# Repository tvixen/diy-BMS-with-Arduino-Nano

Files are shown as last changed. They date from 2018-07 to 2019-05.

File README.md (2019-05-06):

## Update 12/3-2019

New PCB version 3.0.8 added. Including gerber files for PCB in .zip file.

## Update 30/11-2018
Final slave module is ready and running. Software has been updated on slaves and master. Big packs of 100 cells, has been added. 
Pictures:
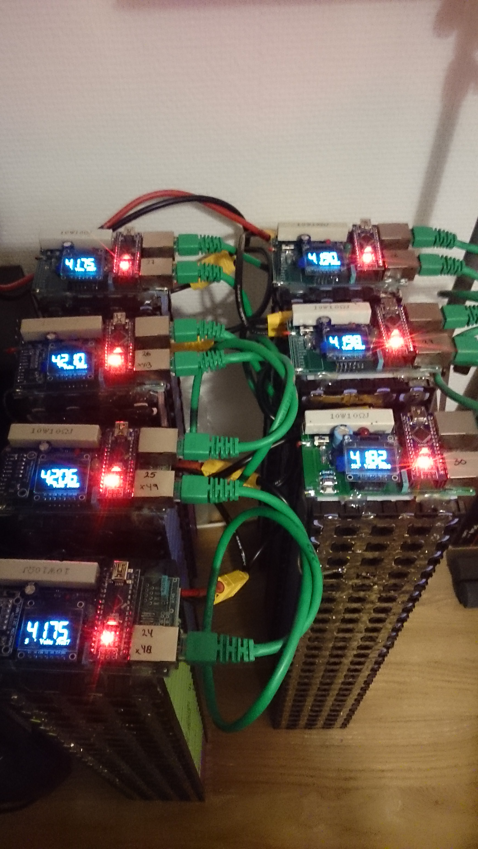
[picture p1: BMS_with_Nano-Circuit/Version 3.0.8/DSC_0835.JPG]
Figure what


## Update 13/7-2018

Arduino code for Master is uploaded. It's purly working as master, and without any debug information. But it should be plug'n play.
Arduino code for Slave is uploaded. No really debug information in code.

## Update 11/7-2018

Feel free to add comments or copy the whole project. It will be updated continuously.....
Next update will be the code for the Master and Slave.
Hardware drawings was updated to 3.0.4

-------------------------------------------------------------------------------------------------------------------------------

# Project "diyBMS with Arduino Nano" (11/7-2018)
Do it yourself battery management system to Lithium ion battery packs/cells
Inspired by Stuart Pittaway, and therefore the credit goes to him.

I was building a powerwall, and for that I needed a sort of batteri management. I have had a look at Batrium, but they was located in the US and the import would be to costly. So I found 
Stuart's project and thourght "This could work". But I was in need of a display and a precise 16bit ADC, so I found some cheap alternatives and added them to the circuit. A new PCB was now under construction.
Then I ordered the parts, and for my big surprise there were no power supply chips or ATtiny85 chips on the marked. So I decided to change the design and use what I had in the drawer. A handful of Arduino Nano.
So therefore this project is designed around the Arduino Nano with a boot sector from the Optiboot project. (no big deal of burning an ordinary Nano with Optiboot) 
The features are also a little different from the original project, as I’m not using the ESP8266 with Wifi, so there will be no transmitting data to a web interface.
Instead the slave modules can show the value of the battery pack (very precise), and the module number itself. The Master will show the status of all the modules, and also send balance commands 
to the module who is sticking out from rest of the packs/cells. + Every module will check if the voltage is over 4.200 volts and balance itself if needed. 

# The design

* One central controller and up to 24 individual cell monitoring nodes.
* The PCB is intented to be sitting in front of a batteri pack with 100.pcs 18650 cells, soldered together with fuses of 1.amp each.
* Use Arduino code, libraries and tools
* Use Arduino Nano as the Master and Slave, so a single PCB can be used as both Master or Slave. 
* Use good connection cables with low noise (twisted pairs)
* The Master will monitoring and control the slaves on the bus.
* The Slave will monitor itself, and discharge if the voltage is higer than 4.200 volts.
* Every single slave will show the pack voltage and the module number on the LED display.
* Ensure each cell voltage is isolated from other cells and that ground voltage is isolated
* Ensure communications between controller and node is isolated
* Keep the coste to a minimum and use whatever theres in the drawer.

# The code

* I did try to use as much of Stuart's origianal code as possible, but had to add a lot of stuff 
* keep it short and simple
* Try not to do inline stuff, as this can be difficult to convert to other platforms/chips

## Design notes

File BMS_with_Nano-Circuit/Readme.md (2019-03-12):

# New PCB files added 12/3-2019

Download the .zip file for the PCB files version 3.0.8.zip

 * "Version 3.0.8"
 
https://github.com/tvixen/diy-BMS-with-Arduino-Nano/blob/master/BMS_with_Nano-Circuit/Version%203.0.8/3.0.8.zip

Pictures for this version:

Figure what

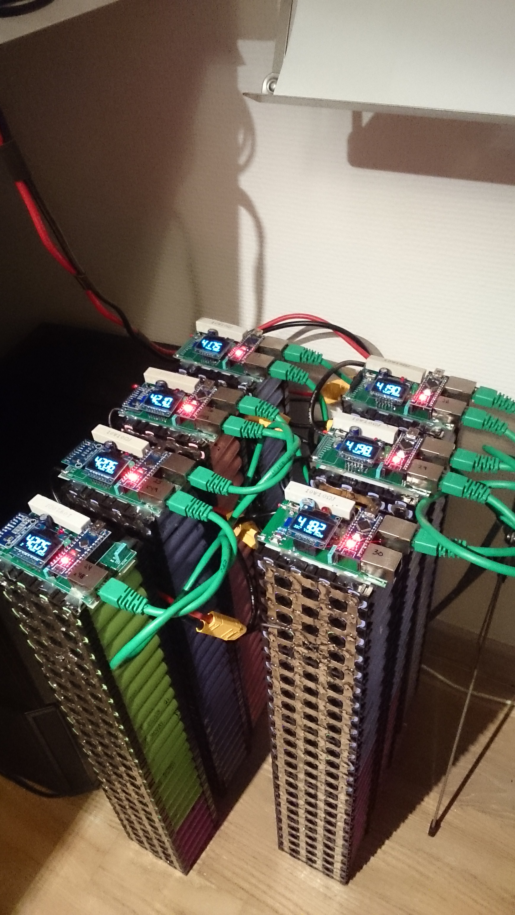
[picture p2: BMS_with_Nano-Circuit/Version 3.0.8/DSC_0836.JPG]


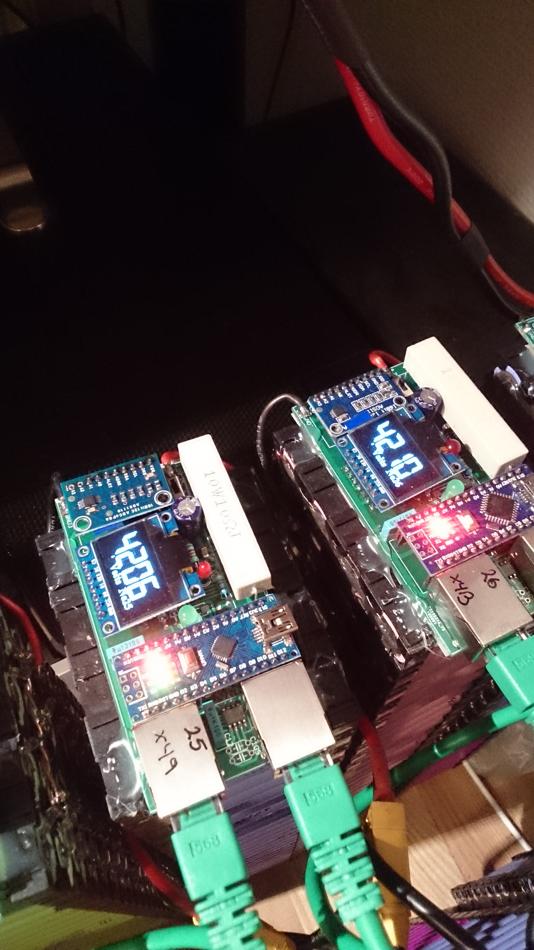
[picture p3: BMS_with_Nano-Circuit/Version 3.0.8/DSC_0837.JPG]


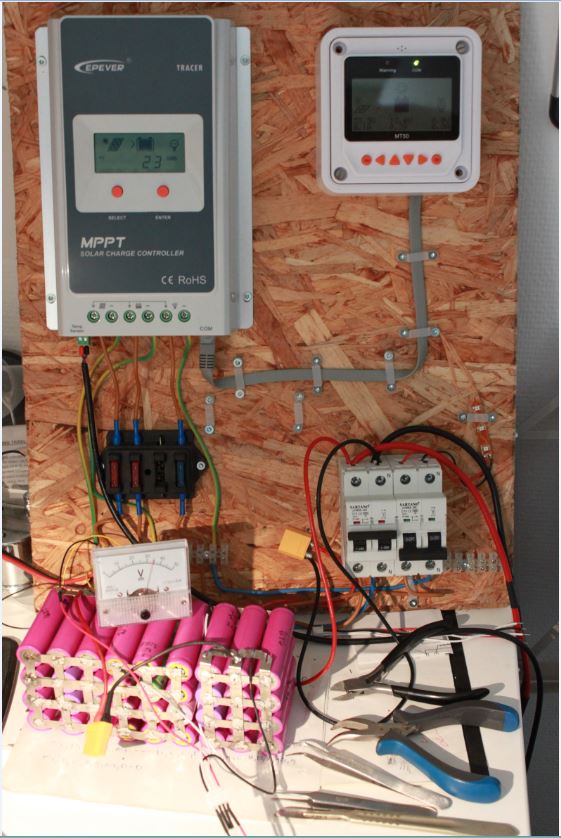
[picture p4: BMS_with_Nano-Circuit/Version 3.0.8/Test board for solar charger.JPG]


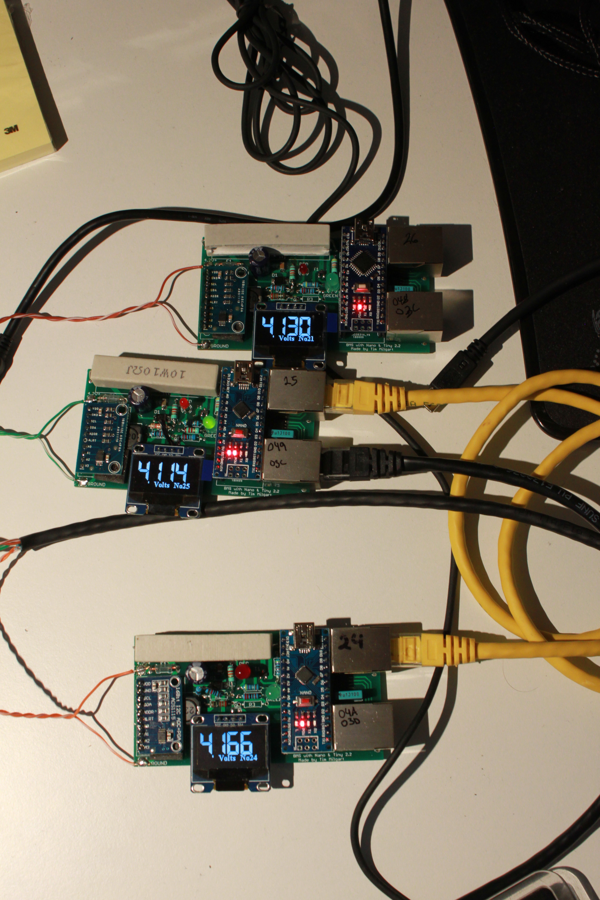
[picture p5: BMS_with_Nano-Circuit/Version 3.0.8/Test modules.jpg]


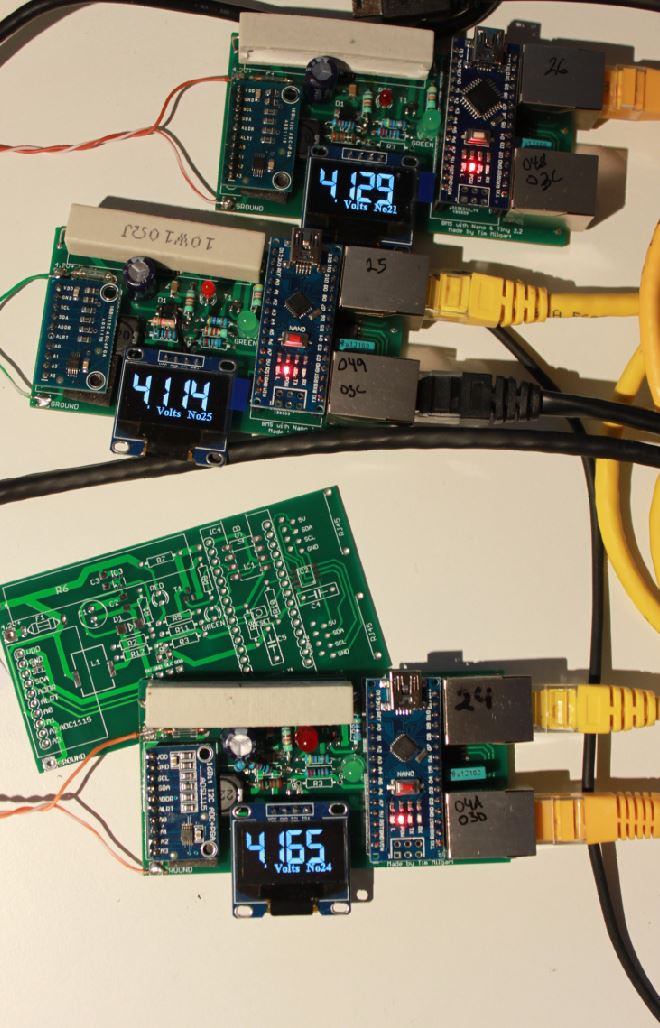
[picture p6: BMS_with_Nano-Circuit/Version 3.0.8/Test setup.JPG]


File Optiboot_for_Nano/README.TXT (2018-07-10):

This is an Optiboot version 6.2 JSON link to put in your Arduino preferences: 
https://github.com/Optiboot/optiboot/releases/download/v6.2/package_optiboot_optiboot-additional_index.json

This is a link to the "Use Arduino as ISP (burner) tutorial:https://www.arduino.cc/en/Tutorial/ArduinoISP

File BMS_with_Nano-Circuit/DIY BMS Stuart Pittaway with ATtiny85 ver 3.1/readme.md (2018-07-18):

# 18/7-2018
New board made with smaller foot print 40*78mm, and now with holes for mounting on 3D printed holder.
Use Stuart's code for this print.

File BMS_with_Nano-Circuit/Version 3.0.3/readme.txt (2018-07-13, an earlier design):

1. The ATTiny85 is now removed. Nano is extreem easy to get on Ebay. AtTiny85 is NOT. 
2. I2C Dispaly is replaced with a SPI Display, to make as little disturbance on the I2C bus as possible. 
3. ADUM1250 is now mounted correct.
4. Added new values to resistors and caps.

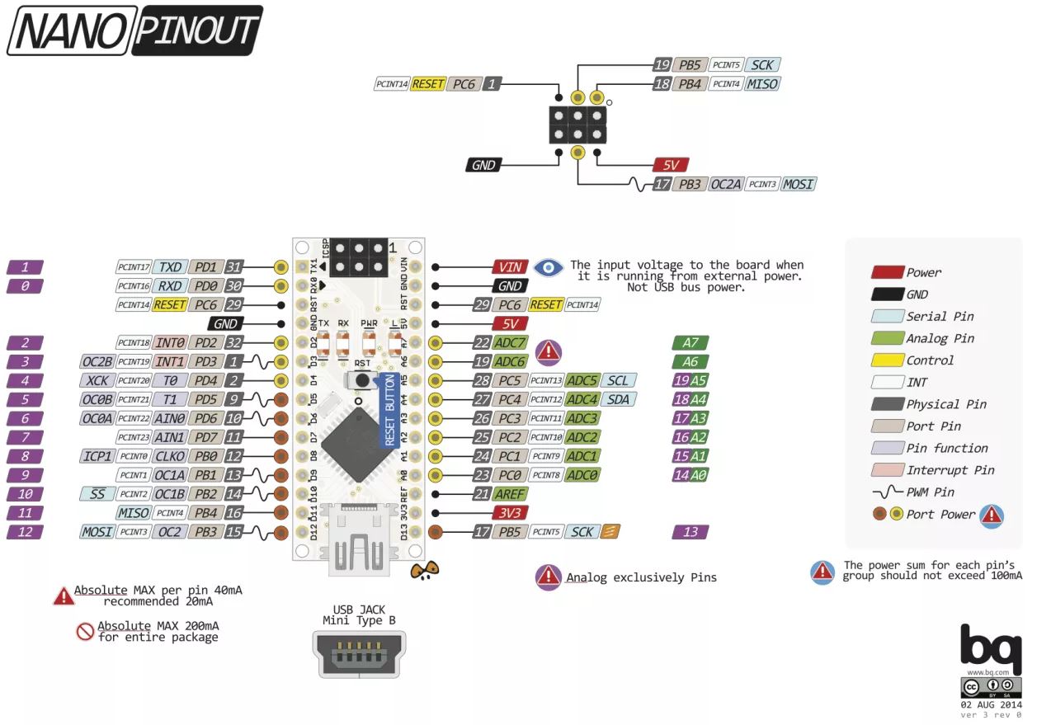
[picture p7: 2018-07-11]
BMS_with_Nano-Circuit/Nano.JPG

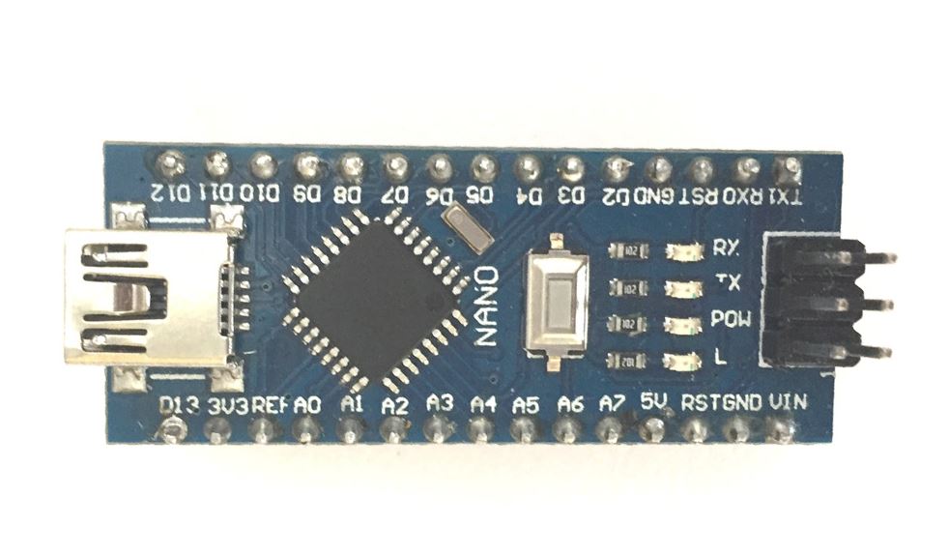
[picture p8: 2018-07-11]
BMS_with_Nano-Circuit/Nano2.JPG

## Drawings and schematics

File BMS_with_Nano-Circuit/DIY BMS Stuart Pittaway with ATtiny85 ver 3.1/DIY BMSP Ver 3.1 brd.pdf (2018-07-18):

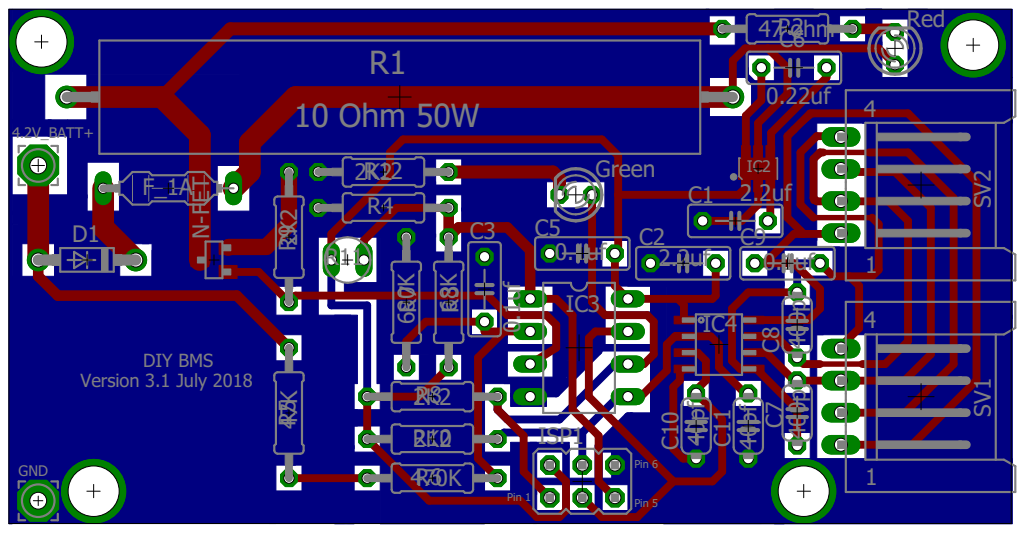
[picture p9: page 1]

GND | | IC3

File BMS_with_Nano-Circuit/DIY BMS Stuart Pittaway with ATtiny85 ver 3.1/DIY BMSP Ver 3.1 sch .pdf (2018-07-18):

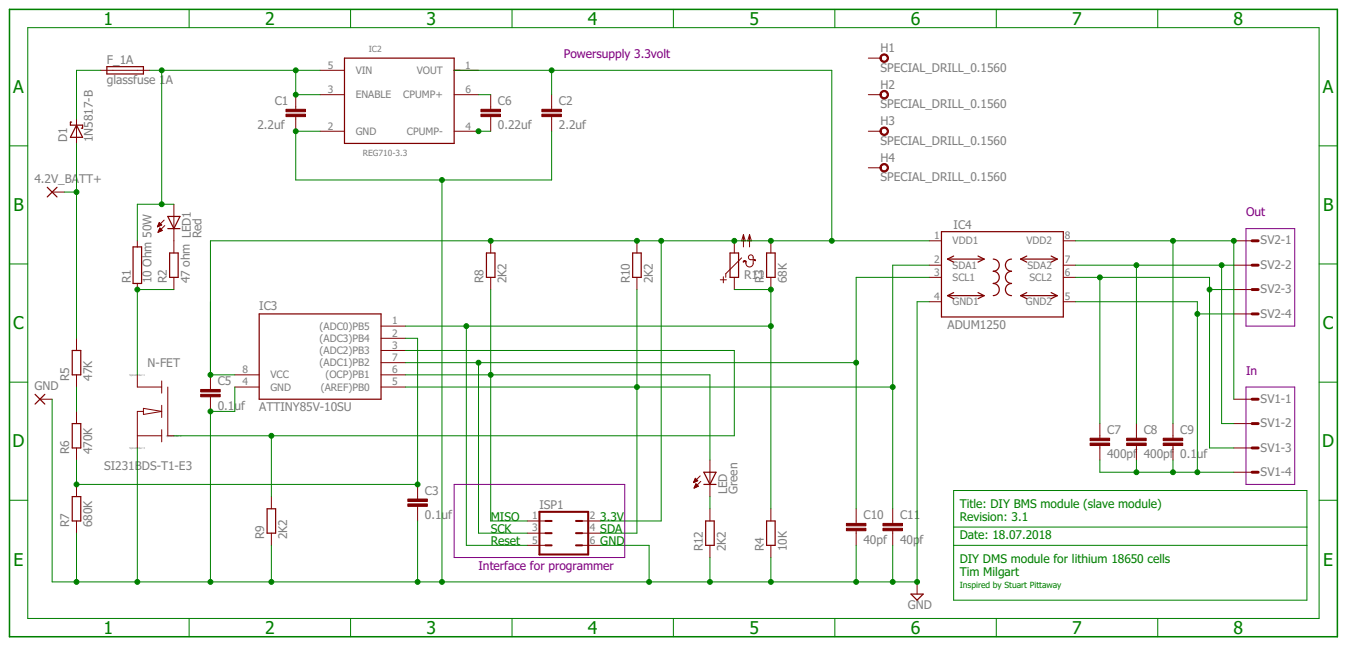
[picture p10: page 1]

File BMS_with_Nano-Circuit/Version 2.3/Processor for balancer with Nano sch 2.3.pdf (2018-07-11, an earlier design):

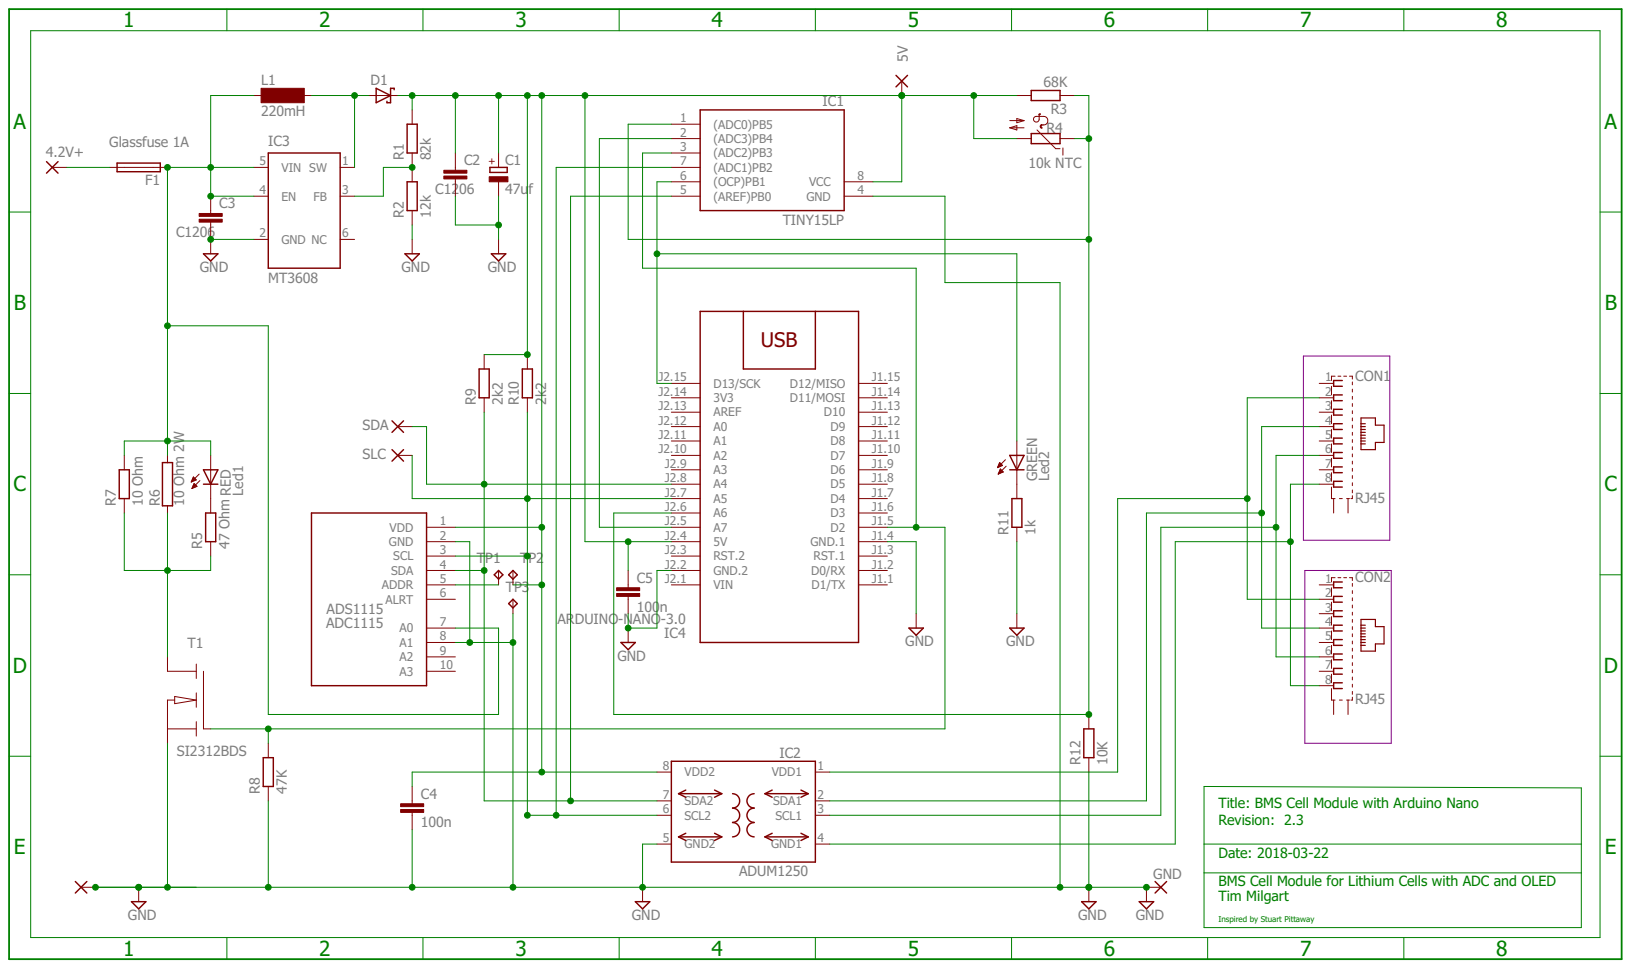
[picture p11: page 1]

Title: BMS Cell Module with Arduino Nano Revision: 2.3

BMS Cell Module for Lithium Cells with ADC and OLED
Tim Milgart

Inspired by Stuart Pittaway

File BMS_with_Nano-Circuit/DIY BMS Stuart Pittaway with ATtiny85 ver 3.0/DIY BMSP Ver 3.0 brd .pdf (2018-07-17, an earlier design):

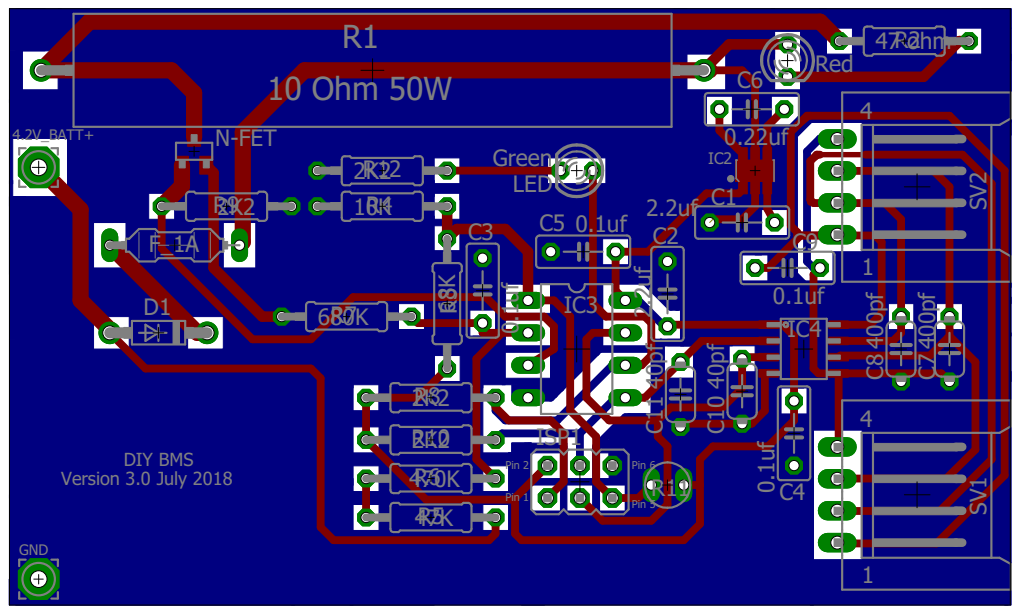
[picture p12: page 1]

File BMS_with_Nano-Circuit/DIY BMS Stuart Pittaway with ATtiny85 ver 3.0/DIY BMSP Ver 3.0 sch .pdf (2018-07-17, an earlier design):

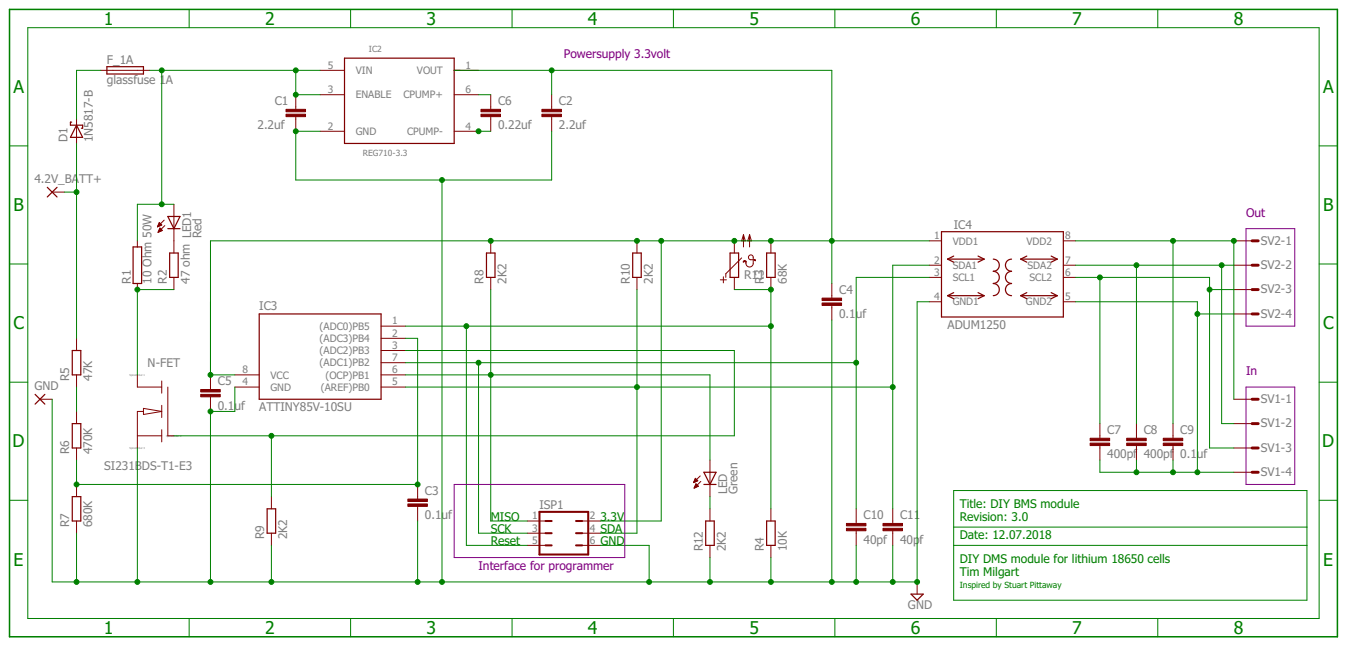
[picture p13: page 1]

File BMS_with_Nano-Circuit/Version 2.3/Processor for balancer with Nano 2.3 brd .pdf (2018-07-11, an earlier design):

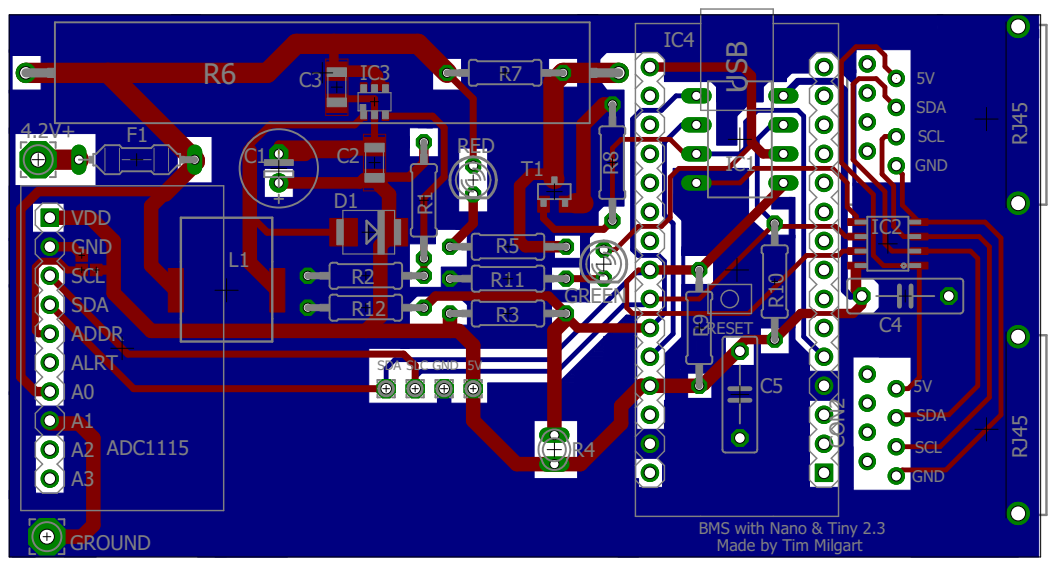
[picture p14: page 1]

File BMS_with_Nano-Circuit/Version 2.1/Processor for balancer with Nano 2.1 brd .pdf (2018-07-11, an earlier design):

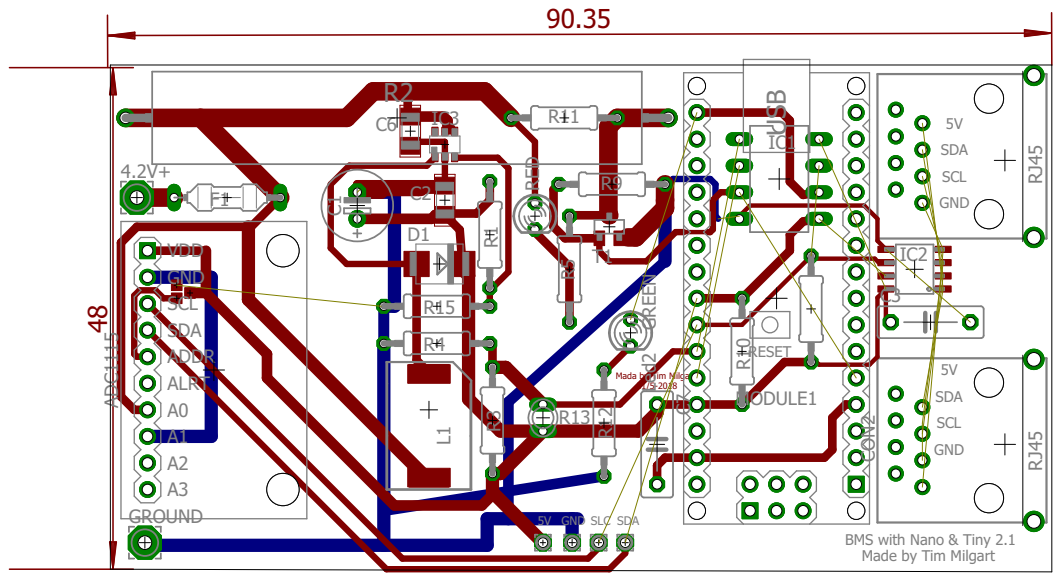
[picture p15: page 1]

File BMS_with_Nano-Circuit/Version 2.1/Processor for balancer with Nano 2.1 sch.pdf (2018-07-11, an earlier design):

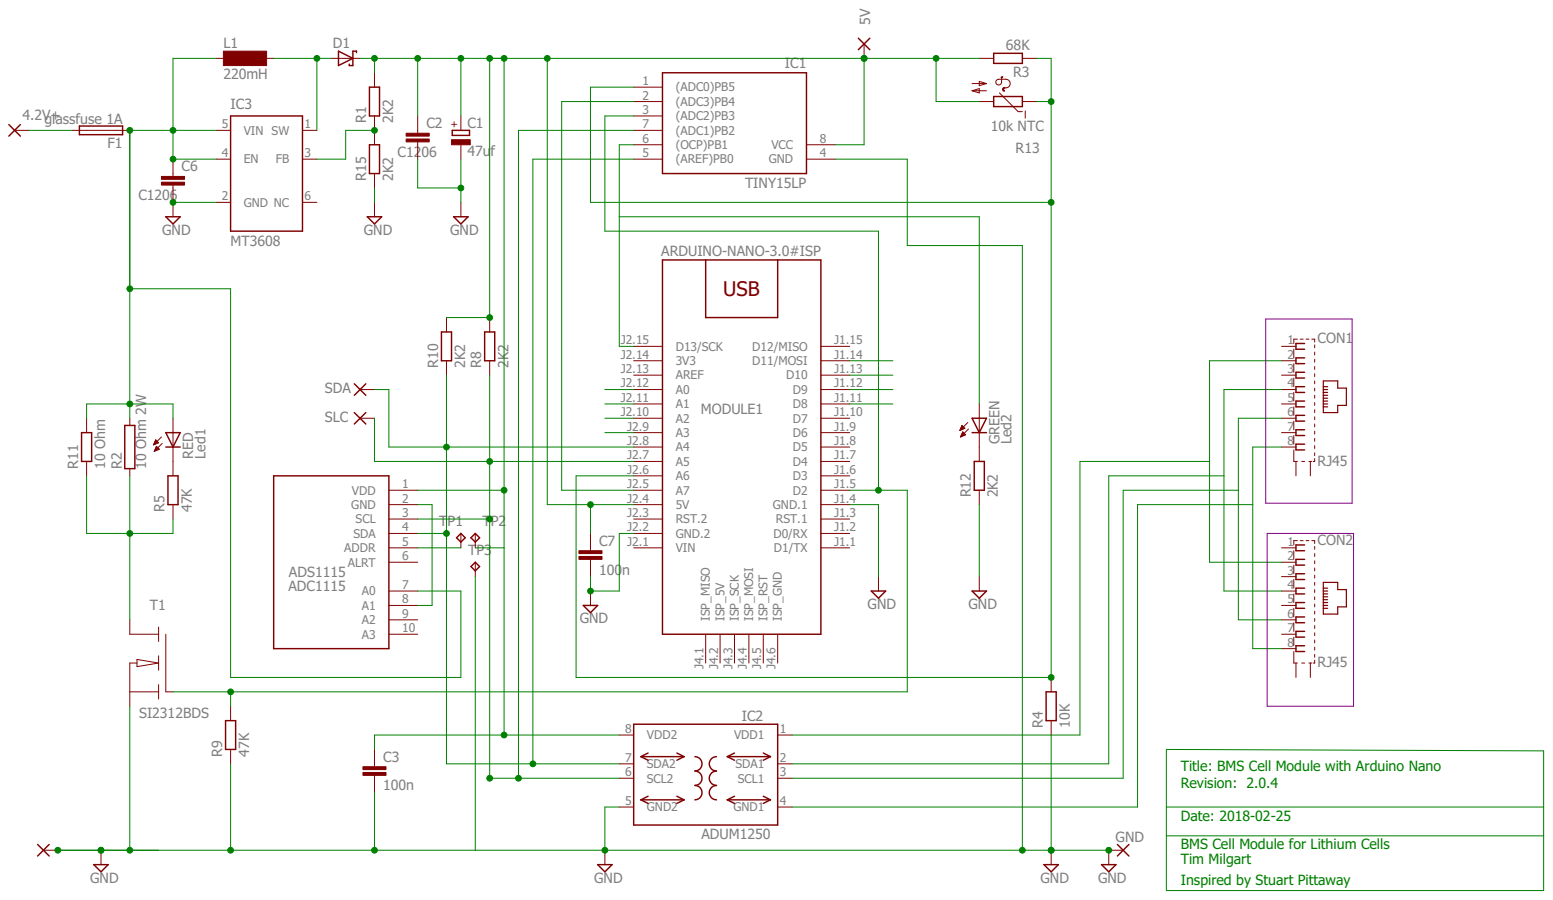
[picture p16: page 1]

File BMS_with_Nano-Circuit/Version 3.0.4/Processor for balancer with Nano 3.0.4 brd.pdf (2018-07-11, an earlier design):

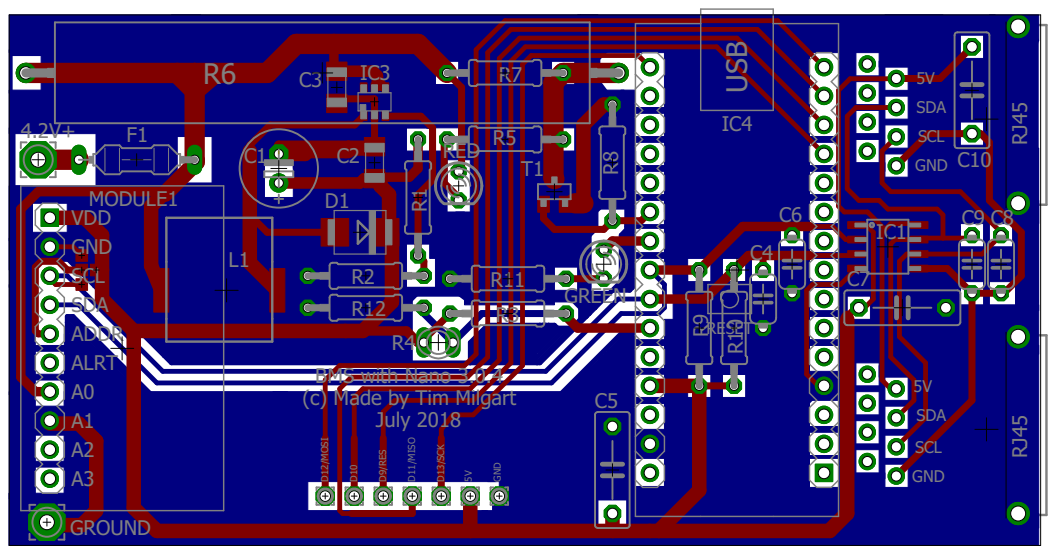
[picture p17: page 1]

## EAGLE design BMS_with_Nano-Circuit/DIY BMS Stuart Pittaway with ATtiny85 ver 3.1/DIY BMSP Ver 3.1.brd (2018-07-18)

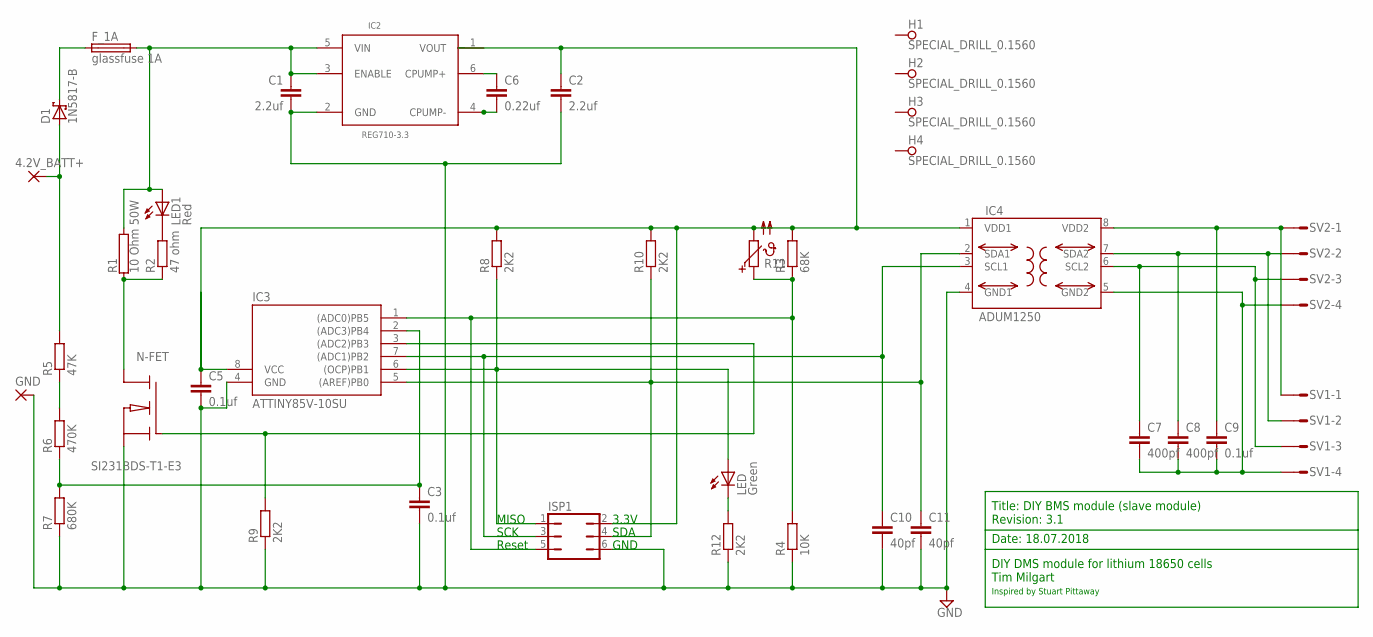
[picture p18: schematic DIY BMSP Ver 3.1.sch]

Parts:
4.2V_BATT+: 3,17/1,3
C1, C2: 2.2uf; C050-025X075
C3, C5, C9: 0.1uf; C050-025X075
C6: 0.22uf; C050-025X075
C7, C8: 400pf; C050-024X044
C10, C11: 40pf; C050-024X044
D1: 1N5817-B; DO41-7.6
F_1A: glassfuse 1A; PICOFUSE
GND: 3,17/1,3
H1, H2, H3, H4: SPECIAL_DRILL_0.1560; PAD_0.1560
IC2: REG710-3.3; SOT-23-6
IC3: ATTINY85V-10SU; DIL08
IC4: ADUM1250; SO8-COOL
ISP1: JP3Q
LED: Green; LED3MM
LED1: Red; LED3MM
N-FET: SI231BDS-T1-E3; SOT23
R1: 10 Ohm 50W; HPS947
R2: 47 ohm; 0207/10
R3: 68K; 0207/10
R4: 10K; 0207/10
R5: 47K; 0207/10
R6: 470K; 0207/10
R7: 680K; 0207/10
R8, R9, R10, R12: 2K2; 0207/10
R11: PTC679; P679
SV1, SV2: L04P

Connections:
GND1: C1.2, C2.2, C3.2, C5.2, C10.2, C11.2, GND.1, IC2.2 (GND), IC3.4 (GND), IC4.4 (GND1), ISP1.6, N-FET.2 (S), R4.1, R7.1, R9.1, R12.1
GND2: C7.2, C8.2, C9.2, IC4.5 (GND2), SV1.4, SV2.4
unnamed: 4.2V_BATT+.1, D1.A, R5.2
unnamed: D1.C, F_1A.1
unnamed: C8.1, IC4.7 (SDA2), SV1.2, SV2.2
unnamed: C6.1, IC2.6 (CPUMP+)
unnamed: C7.1, IC4.6 (SCL2), SV1.3, SV2.3
unnamed: IC3.3 ((ADC2)PB3), N-FET.1 (G), R9.2
unnamed: LED.K (C), R12.2
unnamed: C10.1, IC3.7 ((ADC1)PB2), IC4.3 (SCL1), ISP1.3
unnamed: C3.1, IC3.2 ((ADC3)PB4), R6.1, R7.2
unnamed: C11.1, IC3.5 ((AREF)PB0), IC4.2 (SDA1), ISP1.4, R10.1
unnamed: R5.1, R6.2
unnamed: C6.2, IC2.4 (CPUMP-)
unnamed: IC3.6 ((OCP)PB1), ISP1.1, LED.A, R8.1
unnamed: IC3.1 ((ADC0)PB5), ISP1.5, R3.1, R4.2, R11.1
unnamed: N-FET.3 (D), R1.1, R2.1
unnamed: LED1.K (C), R2.2
unnamed: C1.1, F_1A.2, IC2.3 (ENABLE), IC2.5 (VIN), LED1.A, R1.2
VDD1: C2.1, C5.1, IC3.8 (VCC), IC4.1 (VDD1), ISP1.2, R3.2, R8.2, R10.2, R11.2
VDD2: C9.1, IC4.8 (VDD2), SV1.1, SV2.1

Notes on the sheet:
Reset
SCK
MISO
SDA
3.3V
GND
Title: DIY BMS module (slave module) Revision: 3.1
Date: 18.07.2018
DIY DMS module for lithium 18650 cells Tim Milgart
Inspired by Stuart Pittaway

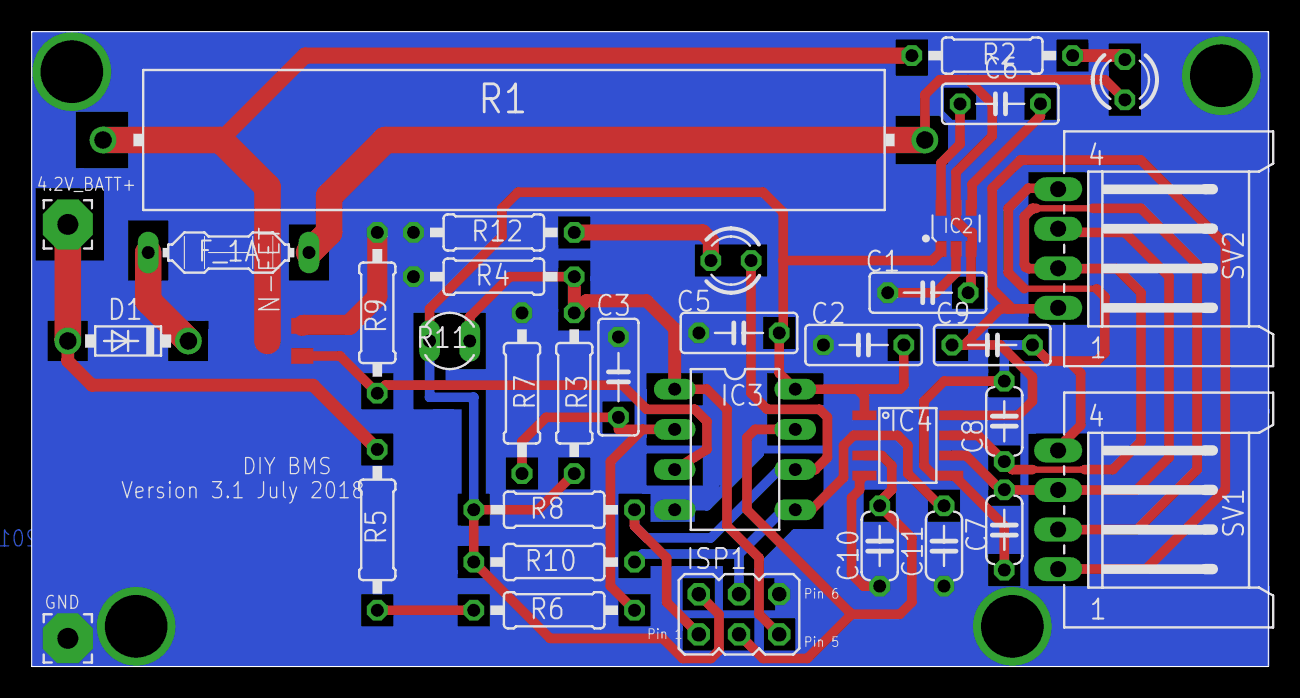
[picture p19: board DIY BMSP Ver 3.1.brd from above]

Board: 2 copper layers, 78.2 x 40.1 mm, 39 parts (0 on the bottom side), 21 nets.

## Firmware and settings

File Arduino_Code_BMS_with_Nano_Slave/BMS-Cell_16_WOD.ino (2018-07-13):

//BMS module software for Arduino Nano
// Version: Arduino IDE 1.8.5  + Cloud
//
// Originally code written by Stuart Pittaway, and heavyly modified by Tim Milgart
//
// Start Date: 13.01.2018
/*
 * This code is supposed to work with a OLED and a 16bit ADC chip called ADS1115
   

   REMEMBER TO CHANGE THE ADDRESS ON THE ADC AND OLED BEFORE UPLOAD !!!   NEW PCB VERSION TO COME!

   This is the code for the Slave - it talks to the Master over isolated i2c bus.  The code will fit into a Arduoni Nano, but the code is compiled for a Uno
   because it will give us some more space, as the bootsection is loaded with Optiboot.
   Update 28/6-2018
   Removed several updates.... 
   Update 02/07-2018
   Removed all GreenLED activities, so it's only my own LED that works. incl inline code for the ATTiny85 chip
   Update 05/07-2018
   Creates brand new design. So only the relevant call is retained.
   3 values are now on the i2c bus.
   Update 05/07-2018 
   Volt and temp is working, but still I2C problems
   Update 06.07.2018
   Added a watchdog...the easy way to get the I2C bus behave
   Sketch uses 16010 bytes (55%) of program storage space. Maximum is 28672 bytes.
   Global variables use 888 bytes (34%) of dynamic memory, leaving 1672 bytes for local variables. Maximum is 2560 bytes. 
   Update 08.07.2018
   Removed unused functions and calls ..still need to remove unused code.
   Update 09.07.2018
   Discovered that the chip is turned around 180 degrees, so the bus side with the high current is pointing towards the cold side of ALUM1250.
   Also the resistors and caps is incorrect. This will be solved in a new version of my PCB. Along with a new SPI display
   Update 12.07.2018
   Added Check_if_OverCharged(). This procedure can turn on the resistor if the voltage is over 4.230 volts 
   Added PackNo, so the module number is showen in the dispaly along with the voltage.
   Update 13.07.2018
   Did a fair cleanup of the code. Deleted some debug information.
   Sketch uses 13510 bytes (41%) of program storage space. Maximum is 32256 bytes.
   Global variables use 865 bytes (42%) of dynamic memory, leaving 1183 bytes for local variables. Maximum is 2048 bytes.
*/


#include <EEPROM.h>
#include <avr/sleep.h>   // til sleep og interrupt
#include <avr/wdt.h>     // watchdog
#include <Wire.h>        // kan tale med Alle Arduino print

#include <Adafruit_ADS1015.h>    // include ADC 1115 
#define I2C_ADC_ADDRESS 0x4A
Adafruit_ADS1115 ads1115(I2C_ADC_ADDRESS);  // construct an ads1115 at address xxx

#include "SSD1306Ascii.h"        // Font for Oled
#include "SSD1306AsciiWire.h"    // Font of Wire for Oled
// 0X3C+SA0 - 0x3C or 0x3D
#define I2C_ADDRESS 0x3C         // Oled address

// Define proper RST_PIN if required.
#define RST_PIN -1              // Reset pin for Oled
SSD1306AsciiWire oled;          // Construct of AsciiWire 


//Where in EEPROM do we store the configuration
#define EEPROM_CHECKSUM_ADDRESS 0
#define EEPROM_CONFIG_ADDRESS 20

#define MIN_BYPASS_VOLTAGE 3000U
#define MAX_BYPASS_VOLTAGE 4200U

//Number of cycles between voltage reading checks (20 = approx 20 seconds)
#define BYPASS_COUNTER_MAX 20

//Default i2c SLAVE address (used for auto provision of address)
#define DEFAULT_SLAVE_ADDR 21

//Configured cell modules use i2c addresses 24 to 48 (24S)
#define DEFAULT_SLAVE_ADDR_START_RANGE 24

//If we receive a cmdByte with BIT 6 set its a command byte so there is another byte waiting for us to process
#define COMMAND_BIT 6

#define COMMAND_factory_default 3
#define COMMAND_set_slave_address 4
#define COMMAND_set_bypass_voltage 8

#define read_voltage 10
#define read_temperature 11
#define read_voltage_calibration 12
#define read_raw_voltage 14
#define read_error_counter 15
#define read_bypass_enabled_state 16

// Port define 
#define DischargePin 2    // Red led
#define GreenLedPin  13   // Green led

volatile float ADCvalue =4.201; //value from ADC
volatile uint16_t results = 0;  //mellem resultat fra ADC
volatile uint16_t temperature_probe = 0;
volatile uint8_t reading_count = 0;
volatile uint8_t cmdByte = 0;
volatile uint8_t last_i2c_request = 255;
volatile uint16_t last_raw_adc = 0;
volatile uint8_t ByPassCounter = 0;
volatile boolean ByPassEnabled = false;
volatile uint16_t TemperaturValue = 0;
volatile uint8_t PacketNo = 0;
volatile bool EventFlag   = false;
uint16_t error_counter = 0;


//Default values
struct cell_module_config 
{
  uint8_t SLAVE_ADDR = DEFAULT_SLAVE_ADDR;
  uint16_t ADC_VCC_Value = 4201;
  uint16_t TemperatureProbe = 10;
};

static cell_module_config myConfig;

void setup() 
{
  Wire.setTimeout(1000);
  Wire.setClock(100000);  //100khz
  Wire.begin();    
  Serial.begin(115200);
  
  pinMode(GreenLedPin, OUTPUT);  //min kode for greenled
  digitalWrite(GreenLedPin, LOW); 
    
  pinMode(DischargePin, OUTPUT); //PB4 = PIN 2  //Mit print siger D2
  digitalWrite(DischargePin, LOW);
  
  wdt_disable(); // not yet

  //3 x blink 
  for (int led=0; led <=6; led++)
   {
     BlinkGreenLed();  //tænder grønled
     delay(200);
   }
  
  //Load our EEPROM configuration, if bad write something
  if (!LoadConfigFromEEPROM()) 
    {
     Serial.println("No Config in EEprom. Module is not initialized = 21");  
     for (int led=0; led <=24; led++)
      {
        BlinkGreenLed();  //tænder grønled
        delay(50);
      }
    }

   //Load our EEPROM configuration, and put it over in our global variables
   PacketNo=myConfig.SLAVE_ADDR;
   last_raw_adc=myConfig.ADC_VCC_Value;
   TemperaturValue=myConfig.TemperatureProbe;

  sei();                  // Enable Global Interrupts
  initOled();             // Oled display startup
  initADC();              // call ads1115.begin();
  ReadTemp();             // read temp
  ReadADC();              // read voltage
  PackNumber();           // Battery pack get its number in the display
  drawVoltage();          // Write to  OLED
  Check_if_OverCharged(); //Check the voltage...is it overcharged

  Serial.println(" Setup done for version Cell Module 16");

  init_i2c();             //init the communication
  wdt_enable(WDTO_4S);    //Watchdog set to 4 sec
}
//----------------------------------------------------------------------------------------------------------------------

boolean inPanicMode = false;
void panic() 
{
  inPanicMode = true;
}
//----------------------------------------------------------------------------------------------------------------------
void loop() 
{
  wdt_reset();           // Watchdog reset
  CheckBypass();         // Check voltage
  ReadTemp();            // Read Temp 
  ReadADC();             // Read ADC
  drawVoltage();         // Read ADCvalue 
  Check_if_OverCharged();// Check battery voltage
  

  if (last_i2c_request > 0) 
   {
     //Count down loop for requests to see if i2c bus hangs or controller stops talking
     last_i2c_request--;
   }

  //If we are on the default SLAVE address then use different LED pattern to indicate this
  if (myConfig.SLAVE_ADDR == DEFAULT_SLAVE_ADDR) // DEFAULT_SLAVE_ADDR=21
   {
     Serial.println("Packet number = 21 = Unconfigured!");
   } 
  else 
   {
     Serial.print("Packet number =");Serial.println(PacketNo);
     if (last_i2c_request == 0 && inPanicMode == false) 
      {
        //Panic after a few seconds of not receiving i2c requests...
        Serial.println("Panic, not receiving i2c requests! = init_i2c");
        panic();

        //Try resetting the i2c bus
        Wire.end();
        init_i2c();
        error_counter++;
      }

     if (last_i2c_request > 0 && inPanicMode == true) 
      {
        inPanicMode = false;
      }
   } //else
}
//----------------------------------------------EEPROM READ/WRITE--------------------------------------------------------------
uint32_t calculateCRC32(const uint8_t *data, size_t length) // used in write & load configtoEEprom
{
  uint32_t crc = 0xffffffff;
  while (length--) {
    uint8_t c = *data++;
    for (uint32_t i = 0x80; i > 0; i >>= 1) {
      bool bit = crc & 0x80000000;
      if (c & i) {
        bit = !bit;
      }
      crc <<= 1;
      if (bit) {
        crc ^= 0x04c11db7;
      }
    }
  }
  return crc;
}

void WriteConfigToEEPROM() {
  EEPROM.put(EEPROM_CONFIG_ADDRESS, myConfig);
  EEPROM.put(EEPROM_CHECKSUM_ADDRESS, calculateCRC32((uint8_t*)&myConfig, sizeof(cell_module_config)));
}

bool LoadConfigFromEEPROM() {
  cell_module_config restoredConfig;
  uint32_t existingChecksum;

  EEPROM.get(EEPROM_CONFIG_ADDRESS, restoredConfig);
  EEPROM.get(EEPROM_CHECKSUM_ADDRESS, existingChecksum);

  // Calculate the checksum of an entire buffer at once.
  uint32_t checksum = calculateCRC32((uint8_t*)&restoredConfig, sizeof(cell_module_config));

  if (checksum == existingChecksum) {
    //Clone the config into our global variable and return all OK
    memcpy(&myConfig, &restoredConfig, sizeof(cell_module_config));
    return true;
  }

  //Config is not configured or gone bad, return FALSE
  return false;
}

void factory_default() {
  EEPROM.put(EEPROM_CHECKSUM_ADDRESS, 0);
}
//------------------------------------------------------------------------------------------------------------

void init_i2c() {
  Wire.begin(myConfig.SLAVE_ADDR);
  Wire.onRequest(requestEvent);
  Wire.onReceive(receiveEvent);
}
//-----------------------------------------REBOOT-------------------------------------------------------------------

void Reboot() 
{
  while (1)     //Infinity loop
  { 
    ledOff(); 
  }
}
//-----------------------------------------BLINK-------------------------------------------------------------------

bool Ledon;
inline void BlinkGreenLed() //LED on or OFF
{ Serial.println("on/off"); 
  if(Ledon)
    digitalWrite(GreenLedPin, HIGH); 
  else
    digitalWrite(GreenLedPin, LOW); 
  Ledon=!Ledon;
}
//-----------------------------------------LED OFF-----------------------------------------------------------------
inline void ledOff() 
{
  digitalWrite(GreenLedPin, LOW); // 2 byte kan spares ved at skrive asm kode i forholdt til digitalwrite
}
//-------------------------------------------SEND-----------------------------------------------------------------
void sendUnsignedInt(uint16_t number) 
{
  Wire.write((byte)((number >> 8) & 0xFF));
  Wire.write((byte)(number & 0xFF));
}

void sendByte(uint8_t number) 
{
  Wire.write(number);
}
//--------------------------------------UNION----------------------------------------------------------------------
union 
{
  uint16_t val;
  uint8_t b[2];
} uint16_t_to_bytes;

uint16_t readUINT16() 
{
  uint16_t_to_bytes.b[0] = Wire.read();
  uint16_t_to_bytes.b[1] = Wire.read();
  return uint16_t_to_bytes.val;
}
//---------------------------------------receiveEvent---------------------------------------------------------------------
// function that executes whenever COMMAND data is received from master
void receiveEvent(int howMany)
{
  if (howMany <= 0) return;
  if (cmdByte != 0) error_counter++;
  cmdByte = Wire.read();
  howMany--;

  if (bitRead(cmdByte, COMMAND_BIT)) 
    {
      bitClear(cmdByte, COMMAND_BIT);
      switch (cmdByte) 
        {
          case COMMAND_factory_default: //3 hvis addresser skal fornyes
           {
             factory_default();
             Reboot();
           }
          break;
          
         case COMMAND_set_slave_address: //4 .. Set i2c slave address and write to EEPROM, then reboot
         if (howMany == 1 ) 
           {
              uint8_t newAddress = Wire.read();
              PacketNo=newAddress;
              if (newAddress != myConfig.SLAVE_ADDR && newAddress >= DEFAULT_SLAVE_ADDR_START_RANGE && newAddress <= 48) 
                {
                  myConfig.SLAVE_ADDR = newAddress;
                  PacketNo=newAddress;
                  WriteConfigToEEPROM();
                  Reboot();
                }
           }
         break;

         case COMMAND_set_bypass_voltage:  // 8  Værdien hvor modstanden skal tænde ... skal være fast, så når det er lavet slettes denne her.
         if (howMany == sizeof(uint16_t)) 
           {
              uint16_t newValue = readUINT16();
              if (newValue >= MIN_BYPASS_VOLTAGE && newValue <= MAX_BYPASS_VOLTAGE ) 
               {
                 ByPassCounter = BYPASS_COUNTER_MAX; //BYPASS_COUNTER_MAX =240
                 ByPassEnabled = true;
               } 
             else 
               {
                 ByPassCounter = 0;
                 ByPassEnabled = false;
               }
           }
         break;
        } //switch (cmdByte)

    cmdByte = 0;
    } 
  else 
    {
      //Its a READ request

      switch (cmdByte) 
       {
         case read_voltage: //10
           {  
             //Serial.print("read_voltage. CmdByte = ");
             //Serial.println(cmdByte);
           }
         break;
       }
    }
  EventFlag=true;
  // clear rx buffer
  while (Wire.available()) Wire.read();
}
//---------------------------------------requestEvent---------------------------------------------------------------------
// function that executes whenever data is requested by master (this answers requestFrom command)
void requestEvent() 
{
  switch (cmdByte) 
   {
     case read_raw_voltage: 
       {
         sendUnsignedInt(last_raw_adc); //14
       } 
     break;

     case read_error_counter: 
       {
         sendUnsignedInt(error_counter); //15
       }
     break;

     case read_bypass_enabled_state: 
       {
         sendByte(ByPassEnabled); //16
       }  
     break;

     case read_temperature: 
       {
         myConfig.TemperatureProbe= TemperaturValue;
         sendUnsignedInt(TemperaturValue); // ved ikke om det her virker
       }
     break;

     case read_voltage_calibration:
       { 
         myConfig.ADC_VCC_Value = last_raw_adc; 
         sendUnsignedInt(myConfig.ADC_VCC_Value);
       }
      break;

 
      default://Dont do anything - timeout
      break;
   }//switch (cmdByte) 

  //Clear cmdByte
  cmdByte = 0;

  //Reset when we last processed a request, if this times out master has stopped communicating with module
  last_i2c_request = 150;
}
//---------------------------------------Temperatur på Batteri---------------------------------------------------------------------
void ReadTemp() //Læs temp fra PTC føler
{
  uint16_t value = 0;  
   
  for(int i=0;i<10;i++)         // taking 10 samples from sensors with a inerval of 2msec and then average the samples data collected
    {
      value   += analogRead(6); //read the voltage from Pin A6
      delay(2);
    }
    
   value=value/10;              //average of the 10 measurements
   TemperaturValue=value/22;    //over in global variable
}
//----------------------------------Balance del--------------------------------------------------------------------------
void CheckBypass()              //control of the voltage, is it too high then the resistance must take over.
{
  
  if (ByPassEnabled)
   { 
     if (ByPassCounter > 0)      // blir 240 når den blir sat
      {
        //We are in ACTIVE BYPASS mode - the RESISTOR will be ACTIVE + BURNING ENERGY
        ByPassCounter--;          //tæl 1 ned
        digitalWrite(DischargePin, HIGH);      //Turn on the power
        Serial.println("ACTIVE BYPASS MODE!");   // test only
      
        if (ByPassCounter == 0)
         {
           digitalWrite(DischargePin, LOW);     //Turn it off again
         }
       }  
    }
  else 
    digitalWrite(DischargePin, LOW);         //Safety check we ensure bypass is always off if not enabled. (Do to communication error)

   
  BlinkGreenLed();                              //turn on the Green LED shows that we have read the Temp
  reading_count++;
}
//------------------------------------------------------------------------------------------------------------
void initADC()
{
  ads1115.begin();                           // start of ADC ADS1115
}
//------------------------------------------------------------------------------------------------------------
void ReadADC()
{
  ADCvalue=0;
  results =0 ;
  
  float multiplier = 0.1876F;                // ADS1115  @ +/- 6.144V gain (16-bit results) 
  results = ads1115.readADC_Differential_0_1();  
 
  ADCvalue=results*multiplier;               // put the result in the float to get all the digits
  last_raw_adc = ADCvalue;                   // convert the flot to an integer
}
//------------------------------------------------------------------------------------------------------------
void initOled() 
{
  
#if RST_PIN >= 0
  oled.begin(&Adafruit128x64, I2C_ADDRESS, RST_PIN);
#else // RST_PIN >= 0
  oled.begin(&Adafruit128x64, I2C_ADDRESS);
#endif // RST_PIN >= 0

  oled.setFont(Verdana12);
  oled.set1X();
  oled.clear();
  oled.setCursor(0,0);
  oled.setLetterSpacing(1);
  oled.print("Made By Tim Milgart");  
  delay(1000);
  oled.clear();  
}
//------------------------------------------------------------------------------------------------------------
void PackNumber()       // Show the number of the module on the screen
{ 
  oled.set1X();
  oled.setFont(TimesNewRoman16_bold);
  oled.clear();
  oled.setCursor(85,6);
  oled.print("No");
  oled.print(PacketNo);
  oled.setCursor(40,6);
  oled.print("Volts");
  oled.setCursor(27,6);
  oled.print("'");
  oled.setFont(lcdnums14x24);
  oled.set2X();
}
//------------------------------------------------------------------------------------------------------------
void drawVoltage(void)    //Show the voltage of the module on the screen
{
if (results>6100)         //Remember the results is without comma... so 5 cifre before comma
  {
    if (EventFlag)        //OLED is only cleared when there has been eventcall ... that is not enough .. still on the head sometimes
      {
        oled.begin(&Adafruit128x64, I2C_ADDRESS);
        oled.set1X();
        oled.setFont(TimesNewRoman16_bold);
        oled.clear();
        oled.setCursor(85,6);
        oled.print("No");
        oled.print(PacketNo);
        oled.setCursor(40,6);
        oled.print("Volts");
        EventFlag=false;
      }
    oled.setCursor(27,6);
    oled.print("'");
    oled.set2X();
    oled.setFont(lcdnums14x24);
    oled.setCursor(0,0);
    Serial.println("-----------------------------------------------------");
    Serial.print("ADC Value ="); Serial.println(ADCvalue); 
    Serial.print("TemperaturValue ="); Serial.println(TemperaturValue); Serial.println();
    Serial.println("-----------------------------------------------------");
    oled.print(ADCvalue,0); 
  } 
else 
  {
    oled.set2X();                              // sætter størrelse på bogstaver
    oled.clear(0 ,128, 0, 5);                  // sletter teksten
    oled.clear(0 ,30, 0, 6);                   // sletter teksten
    oled.setFont(TimesNewRoman16_bold);        // sæt ny font   
    oled.setCursor(0,1);                       // placer cursor
    oled.print("No input    ");                // skriv på skærm
    delay(500);
    oled.clear(0 ,128, 0, 5);                  // sletter teksten
    oled.set1X();                              // sætter størrelse på bogstaver
    oled.setCursor(25,1);                      // placer cursor
    oled.print("Made By ");                    // skriv på skærm
    oled.setCursor(15,3);                      // placer cursor
    oled.print("Tim Milgart ");                // skriv på skærm
  }
}
//------------------------------------------------------------------------------------------------------------
void Check_if_OverCharged() // This is done as an additional local security for overvoltage and has nothing to do with balance.
{
  if (results>22640) 
    {
      
      digitalWrite(DischargePin, HIGH);   //Start discharge
      Serial.println("DISCHARGING !!!");
      delay(1000);                        //lets give it some time to discharge 
    } 
  else 
    {  
     if (!ByPassEnabled)
     digitalWrite(DischargePin, LOW);     //Stop discharge
     delay(1000);                         //Cool down 
    } 
}
//------------------------------------------------------------------------------------------------------------

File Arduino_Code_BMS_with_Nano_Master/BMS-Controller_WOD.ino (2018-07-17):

//BMS controller software for Arduino Nano
// Version: Arduino IDE 1.8.5  + Cloud
//
// Originally code written by Stuart Pittaway, and heavyly modified by Tim Milgart
//
// Start Date: 13.01.2018
//
// Update: 05-02-2018
// (c) 2018 Tim Milgart 
// This is the cleanest code for the controller called Master - it talks to the cell modules over isolated i2c bus.  The code will fit into a Arduoni Nano, It can be compiled for a Uno
// as this it will give us some more storage space, as the bootsection is loaded with Optiboot.
// There is a second code with lots of features, OLED display aso. But this is the clean one. If the modules have the corect addresses, it will same some time.
// Update 03.04.2018
// Sketch uses 9866 bytes (32%) of program storage space. Maximum is 30720 bytes. Global variables use 1400 bytes (68%) of dynamic memory, leaving 648 bytes for local variables. Maximum is 2048 bytes.
// Need to optimize a bit and remove lots of unused functions and calls  
// Done with BusInit, Should give a new number to a new module
// Sketch uses 9742 bytes (33%) of program storage space. Maximum is 28672 bytes.
// Global variables use 1193 bytes (46%) of dynamic memory, leaving 1367 bytes for local variables. Maximum is 2560 bytes.
// Update 03.06.2018
// New name "BMS-Controller_12"
// Done with SortByVolt, so it will turn-on the resistorn if one module is 0,05v over the lowest module
// Sketch uses 7906 bytes (27%) of program storage space. Maximum is 28672 bytes.
// Global variables use 850 bytes (33%) of dynamic memory, leaving 1710 bytes for local variables. Maximum is 2560 bytes. 
// Update 03.07.2018
// optimized a bit still much shit to be deleted  
// Sketch uses 8302 bytes (27%) of program storage space. Maximum is 30720 bytes.
// Global variables use 1427 bytes (69%) of dynamic memory, leaving 621 bytes for local variables. Maximum is 2048 bytes.
// Update 09.07.2018
// Added a watchdog, as the bus tend to hang 
// Update 10.07.2018
// Removed unused functions and calls, added a sort algorithm...still need remove unused code, and make a proper init. 
// Update 12.07.2018
// Made a counter for the on-time of the module with the active resistor. So there will be no fire or hot resistor.
// Update 13.07.2018
// Cleaned up in debug information. All serial communication removed
// Sketch uses 6398 bytes (19%) of program storage space. Maximum is 32256 bytes.
// Global variables use 640 bytes (31%) of dynamic memory, leaving 1408 bytes for local variables. Maximum is 2048 bytes.



// the I2C communication
#include <Wire.h>

// watchdog
#include <avr/wdt.h>     

//Inter-packet/request delay on i2c bus
#define delay_ms                              20

#define COMMAND_BIT                           6

#define COMMAND_factory_default               3
#define COMMAND_set_slave_address             4
#define COMMAND_set_temperature_calibration   7
#define COMMAND_set_bypass_voltage            8

#define read_voltage                          10
#define read_temperature                      11
#define read_raw_voltage                      14
#define read_error_counter                    15
#define read_bypass_enabled_state             16

//Default i2c SLAVE address/Unconfigurated 
#define DEFAULT_SLAVE_ADDR                    21
#define NUMBER_MODULES_IN_THE_SYSTEM           7
#define BYPASS_TIME                           15 //30.sec
#define MODULE_VOLT_DIFFERENCE                50 //milli volt
 
//Configured cell modules use i2c addresses 24 to 48 (24S)
#define DEFAULT_SLAVE_ADDR_START_RANGE        24
#define DEFAULT_SLAVE_ADDR_END_RANGE DEFAULT_SLAVE_ADDR_START_RANGE + 24 

union {uint16_t val; uint8_t buffer[2];} uint16_t_to_bytes;  
const byte MODULE_ID = NUMBER_MODULES_IN_THE_SYSTEM;
const byte COUNT = NUMBER_MODULES_IN_THE_SYSTEM;
volatile uint8_t Counter_for_Bypass  = BYPASS_TIME;
typedef struct cell_module {int volt; byte id;} records; records celledata[COUNT]; 
uint8_t i=0;

//----------------------------------------------SEND COMMANDO-----------------------------------------------------------------------
//Send only 2 values.   1=cell_id 2=cmd 
uint8_t  send_command(uint8_t cell_id, uint8_t cmd) 
{
  Wire.beginTransmission(cell_id); // transmit to device
  Wire.write(cmd);  //Command configure device address
  uint8_t ret = Wire.endTransmission();  // stop transmitting
  delay(delay_ms);
  return ret;
}

//Send 3 values, the last with int8. 1=cell_id 2=cmd 3=value
uint8_t  send_command(uint8_t cell_id, uint8_t cmd, uint8_t byteValue) 
{
  Wire.beginTransmission(cell_id); // transmit to device
  Wire.write(cmd);  //Command configure device address
  Wire.write(byteValue);  //Value
  uint8_t ret = Wire.endTransmission();  // stop transmitting
  delay(delay_ms);
  return ret;
}
//Send 3 værdier, den sidste med int16.  1=cell_id 2=cmd 3=værdien
uint8_t send_command(uint8_t cell_id, uint8_t cmd, uint16_t Value) 
{
  uint16_t_to_bytes.val = Value;
  Wire.beginTransmission(cell_id); // transmit to device
  Wire.write(cmd);  //Command configure device address
  Wire.write(uint16_t_to_bytes.buffer[0]);
  Wire.write(uint16_t_to_bytes.buffer[1]);
  uint8_t ret = Wire.endTransmission();  // stop transmitting
  delay(delay_ms);
  return ret;
}
//--------------------------------------------------COMMAND_BIT-------------------------------------------------------------------
uint8_t cmdByte(uint8_t cmd) 
{
  bitSet(cmd, COMMAND_BIT);
  return cmd;
}
//--------------------------------------------------READ VALUES-------------------------------------------------------------------
//receive 3 values, first with int16
uint16_t read_uint16_from_cell(uint8_t cell_id, uint8_t cmd) 
{
  send_command(cell_id, cmd);
  uint8_t status = Wire.requestFrom((uint8_t)cell_id, (uint8_t)2);
  uint8_t buffer[4];
  buffer[0] = (uint8_t)Wire.read();
  buffer[1] = (uint8_t)Wire.read();
  delay(delay_ms);
  return word(buffer[0], buffer[1]);
}
//modtag 3 værdier første med int8
uint8_t read_uint8_t_from_cell(uint8_t cell_id, uint8_t cmd) {
  send_command(cell_id, cmd);
  uint8_t status = Wire.requestFrom((uint8_t)cell_id, (uint8_t)1);
  uint8_t buffer = (uint8_t)Wire.read();
  delay(delay_ms);
  return buffer;
}
//-----------------------------------------------COMMAND CALLS----------------------------------------------------------------------
uint8_t command_factory_reset(uint8_t cell_id) 
{
  return send_command(cell_id, cmdByte( COMMAND_factory_default )); 
}

//1=cell_id 2=cmd 3=ny adresse
uint8_t command_set_slave_address(uint8_t cell_id, uint8_t newAddress) 
{
  return send_command(cell_id, cmdByte( COMMAND_set_slave_address ), newAddress);
}

uint8_t command_set_bypass_voltage(uint8_t cell_id, uint16_t  value) 
{
  return send_command(cell_id, cmdByte(COMMAND_set_bypass_voltage), value);
}
//-----------------------------------------------READ CALLS----------------------------------------------------------------------
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

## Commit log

2018-07-17 Add files via upload
    Stuart's original design, with normal resistors and caps. (the ones you have in your drawer)
    [DIY BMSP Ver 3.0.brd, DIY BMSP Ver 3.0.sch]
2018-07-17 switched some lines
2018-07-18 Add files via upload
    New board made with smaller foot print 40*78mm, and now with holes for mounting on 3D printed holder.
    [DIY BMSP Ver 3.1.brd, DIY BMSP Ver 3.1.sch]
2018-11-29 Add files via upload
    In this version the display has changed to SPI (5 pins) as I coulden't address 7 OLED's at the same I2C BUS.
    There's still one master (number 24) and 6 slaves. The batteri pack is now expanded to 7S100. 7 packs with 100 cells inside.
